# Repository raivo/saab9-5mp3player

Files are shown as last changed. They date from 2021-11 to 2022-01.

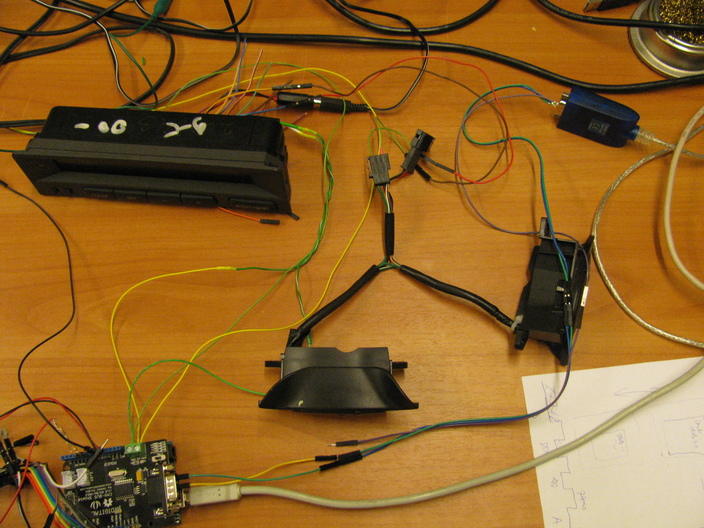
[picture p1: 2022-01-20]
images/IMG_0596.JPG

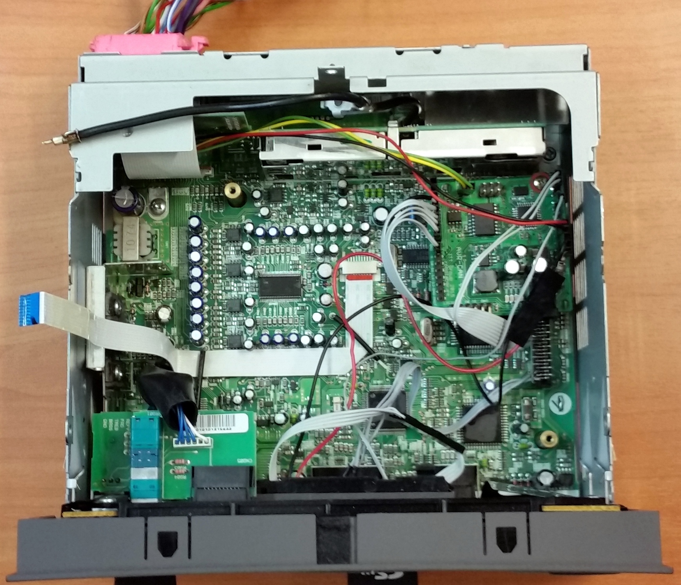
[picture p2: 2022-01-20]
images/20160216_161045.jpg

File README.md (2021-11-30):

# saab9-5mp3player
SAAB 9-5 OG MP3 player for original head unit

MP3 player upgrade for SAAB 9-5 OG OEM stereo

Description

MP3 module for SAAB 9-5 original stereo is a set of hardware and software specially designed for SAAB 9-5 (1998-2005) by replacing old Tape module with new MP3 music player. Music can be played from SD card, USB stick or Aux in (e.g. phone, etc.). MP3 player is controlled over steering wheel buttons and SID buttons. As an option it is possible to have also IR remote control function.

MP3 player fits to SAAB 9-5 model years 1998-2005 without navigation and with Tape module.

Features
Playing MP3 music from SD-card or USB stick
Audio input (Aux in) standard 3,5 mm plug
Equalizer (4 channels)
Song repeat
Next and previous song switching
Moving forward by 10 songs
Some information is showed in SID

Functionality

Steering wheel buttons
SEEK >>	Next song
SEEK <<	Previous song
NXT	10 song forward	Every press moves 10 songs forward
NXT (3 sec)	Moving to song nr.1	Sound signal on SID
SRC (TAPE)	MP3 player ON	LED will switch ON on MP3 player panel. During playback LED is blinking.

SID
SET	Equalizer	Short sound notification on SID
CLEAR	Repeat on/off	Short sound notification on SID

Connection
Module consists of AVR-CAN microcontroller, MP3 player, panel (3D printed), cables and fastenings needed for installation. MP3 Player is installed into Tape insert socket and microcontroller replacing the mechanical tape mechanism inside the stereo. Installation needs electronic skills, including soldering and reading electronic documentation.

Video: https://youtu.be/o2rh0J5VbTw

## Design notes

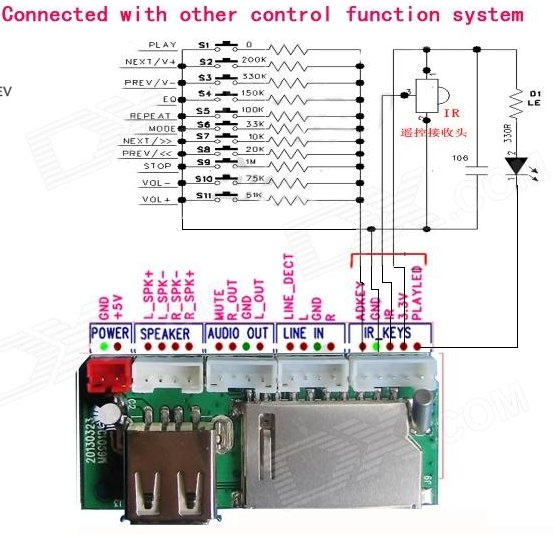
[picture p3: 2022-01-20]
images/MP3_player.jpg

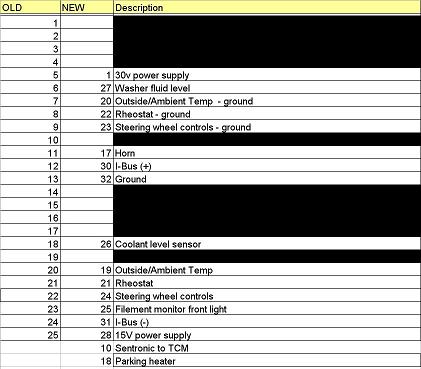
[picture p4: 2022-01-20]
images/SID_ühendused.jpg

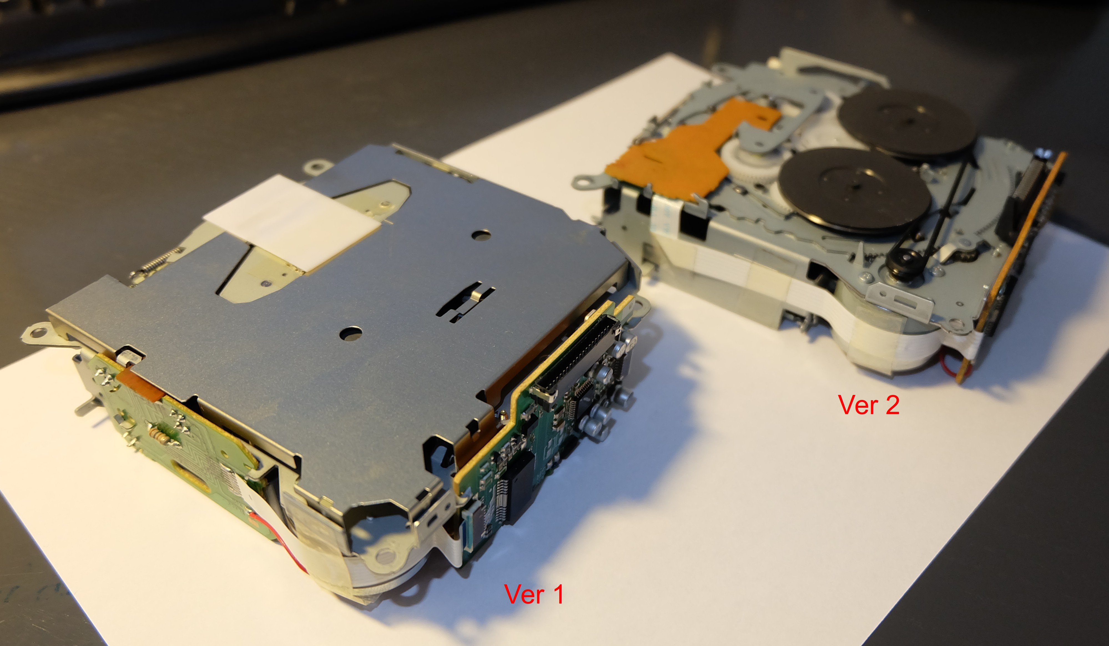
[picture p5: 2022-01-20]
images/Saab95_tapes_side.JPG

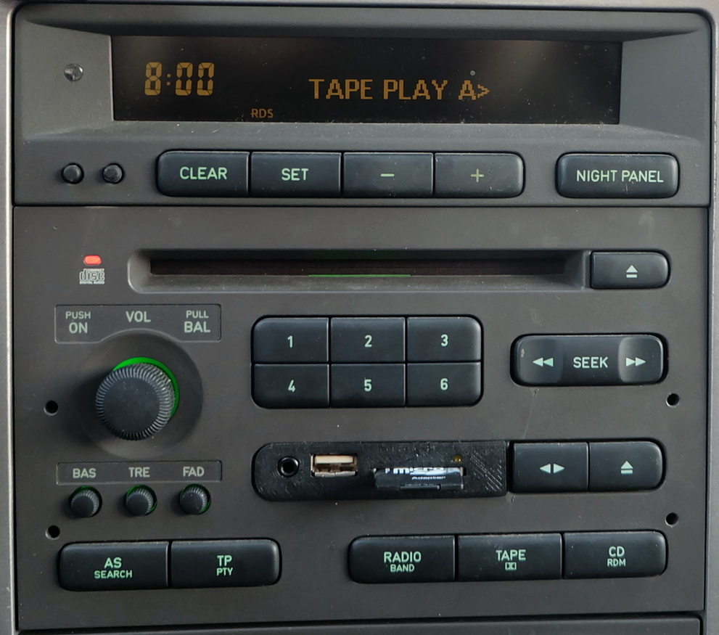
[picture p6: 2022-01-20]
images/makk.JPG

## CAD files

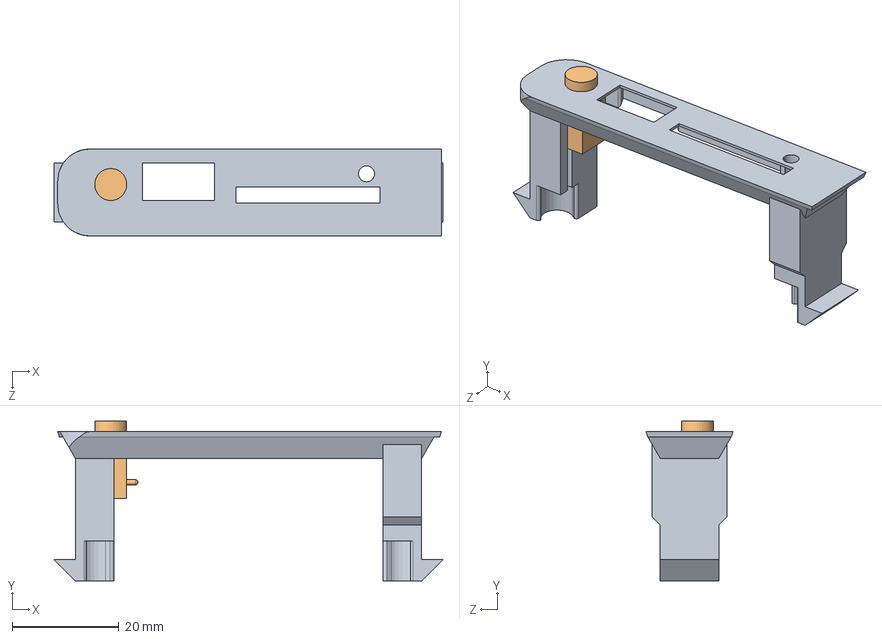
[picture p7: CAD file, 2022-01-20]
cad/Assem1.SLDASM
73.0 x 30.0 x 16.3 mm
Korpus
Stereo

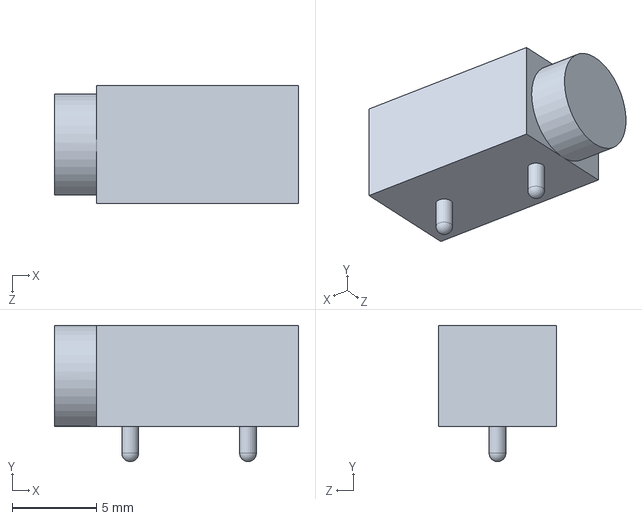
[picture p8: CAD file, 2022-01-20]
cad/Stereo.SLDPRT
14.5 x 8.10 x 7.00 mm

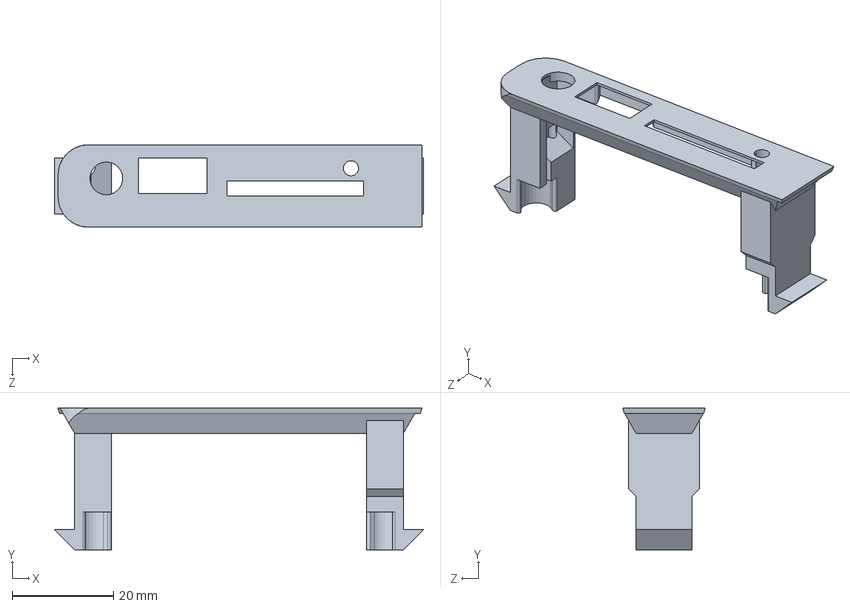
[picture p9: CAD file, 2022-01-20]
cad/Korpus.SLDPRT
73.0 x 28.0 x 16.3 mm

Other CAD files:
cad/Korpus.STL

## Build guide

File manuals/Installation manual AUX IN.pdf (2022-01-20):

# Installation manual

## AUX input for SAAB 9-5 original stereo

AUX input for SAAB 9-5 original stereo instead of TAPE player. During the installation Tape unit will be removed from STEREO unit and will be no longer available. Instead AUX input is used and Tape functionality will be simulated to head unit to avoid audio cut off and tape error.

The product includes tape simulator hardware and software, 3.5 mm audio input connector, necessary cables and fastenings.

NB! Wherever possible we recommend to order installation from manufacturer, please contact with info@ittgroup.ee or by phone +3726566614 for more information. Following this manual is in your own risk and ITT Group is not taking any responsibilities of damage your unit or even car data communication system.

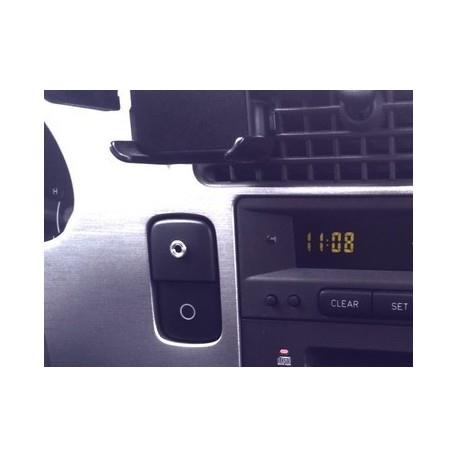
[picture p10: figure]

Document version 1.0

Date 02/2106

ITT Group
Akadeemia tee 21, Tallinn, Estonia
+3725163560, info@ittgroup.ee
Video guide is available in youtube channel: www.youtube.com/ittgrouptallinn

### STEP 1. Identify TAPE version and unsolder main connector plug

Before the installation (and order) one must identify the TAPE version fitted into STEREO unit. Older versions (Ver 1) have different signal logic and tape connector compared with newer version (Ver 2). According to the version different TAPE simulator software is needed for controller. This information have to be sent to manufacturer before product can be sent out to customer.

Images below help to identify the TAPE version inside the STEREO unit.

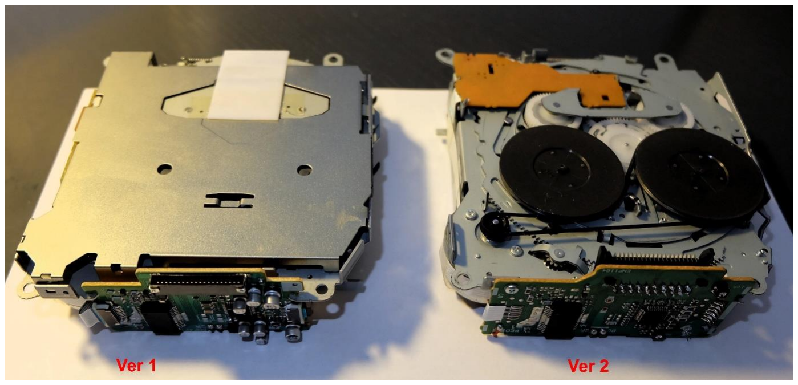
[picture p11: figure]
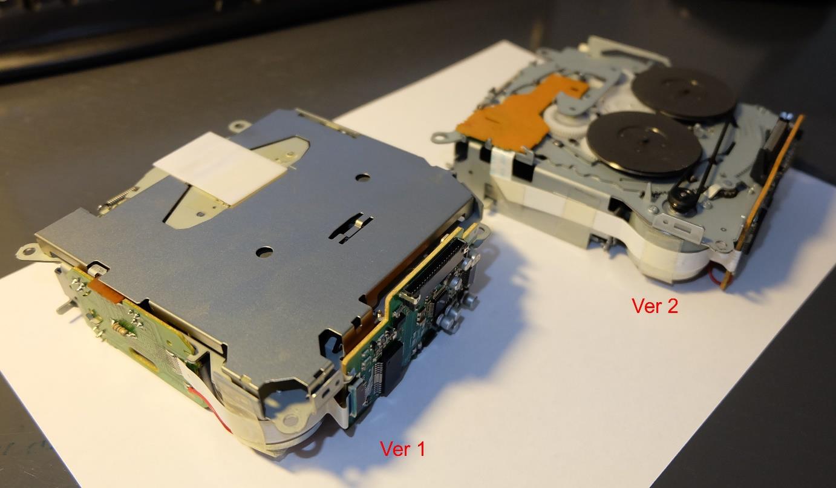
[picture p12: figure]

After removing TAPE player unsolder the main connector on the deck board. TAPE player itself is not needed anymore.

### STEP 2. Solder TAPE Simulator cable

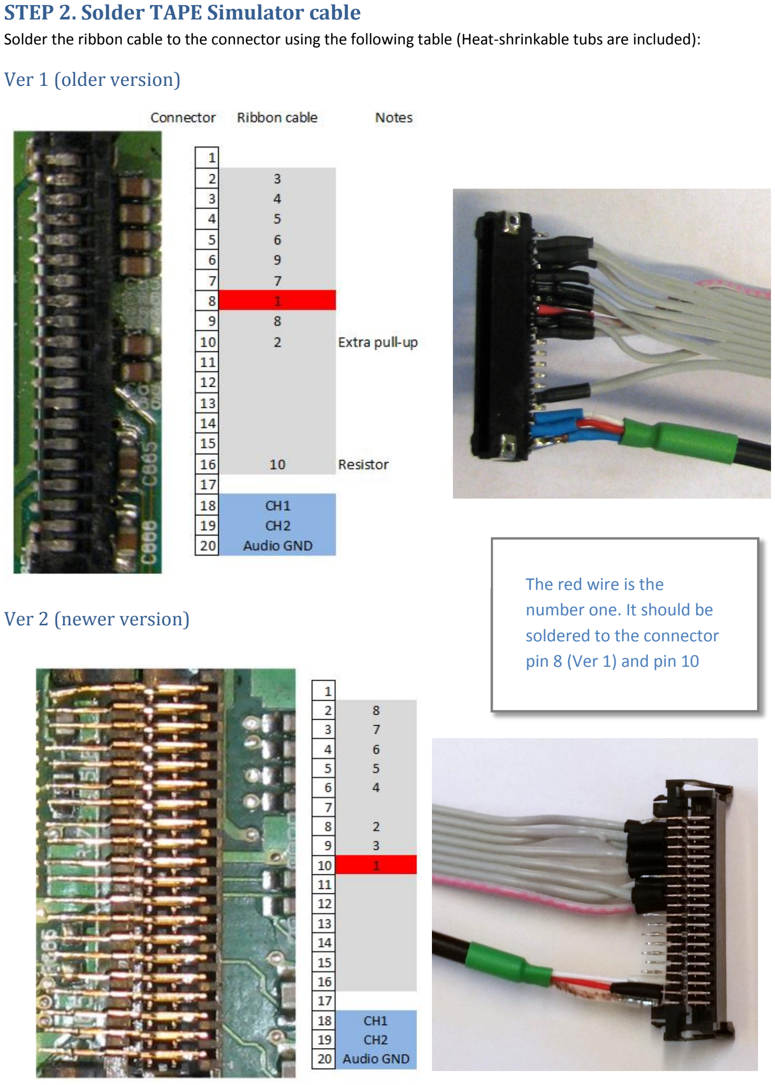
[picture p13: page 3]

The red wire is the
number one. It should be
soldered to the connector
pin 8 (Ver 1) and pin 10

Solder the ribbon cable to the connector using the following table (Heat-shrinkable tubs are included):

### Ver 1 (older version)

### Ver 2 (newer version)

### STEP 3 Solder power cables

Power is taken from remote antenna output. Power cables are soldered to the main STEREO connector board on the back side of unit.

NB! CAN cables are not needed for this case as seen in picture!

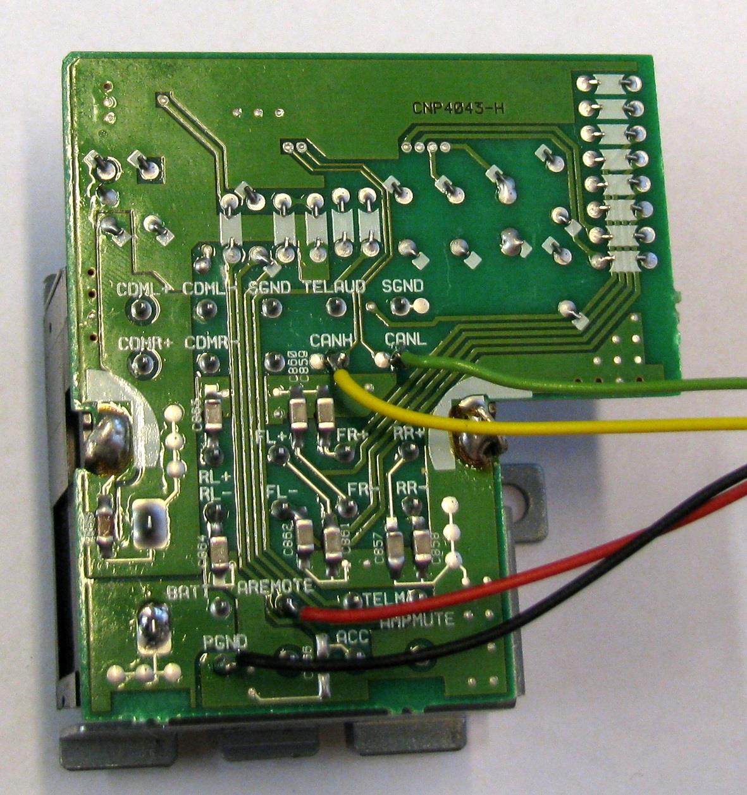
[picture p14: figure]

### STEP 4 Connect simulator plug and install the controller board

### Ver 2 Ver 1

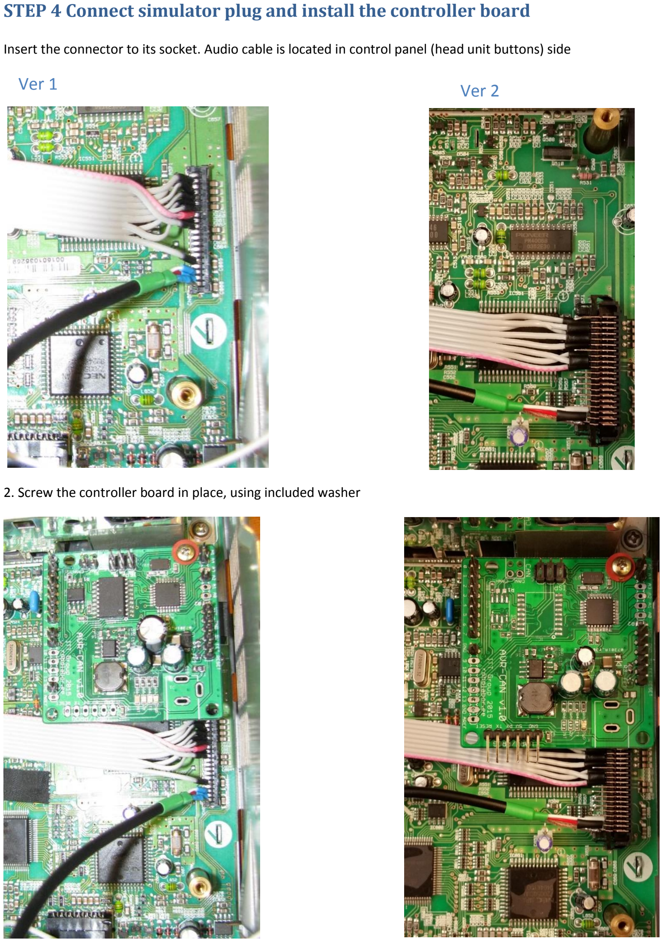
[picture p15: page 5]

Insert the connector to its socket. Audio cable is located in control panel (head unit buttons) side

2. Screw the controller board in place, using included washer

### STEP 5 Connect all wires to controller board

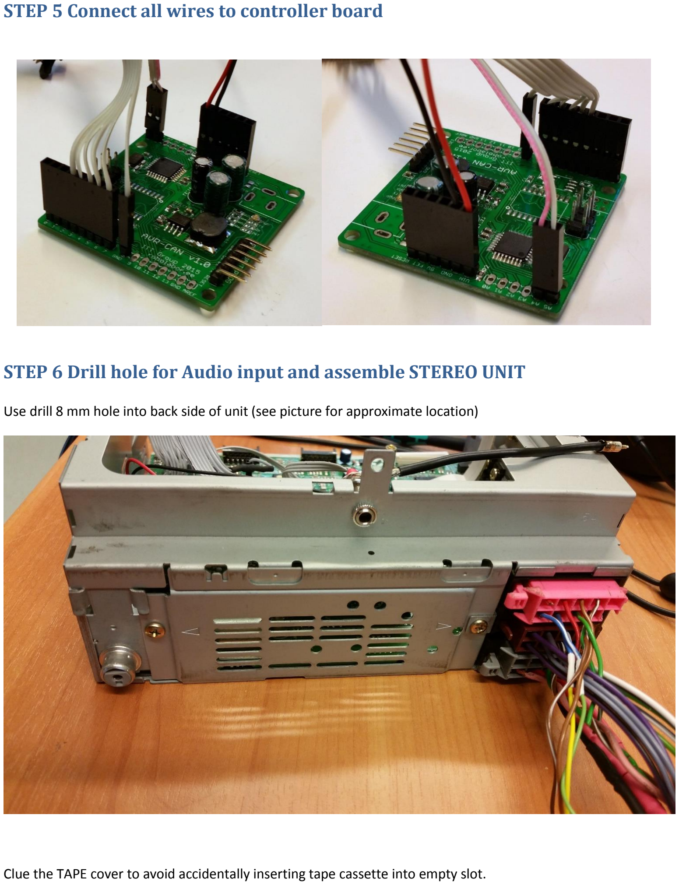
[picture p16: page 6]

### STEP 6 Drill hole for Audio input and assemble STEREO UNIT

Use drill 8 mm hole into back side of unit (see picture for approximate location)

Clue the TAPE cover to avoid accidentally inserting tape cassette into empty slot.

Make frontend socket for AUX IN (e.g. empty button slot)

Example:

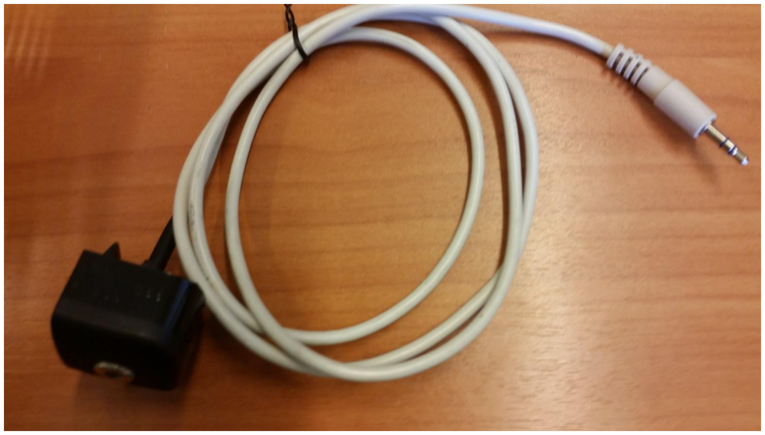
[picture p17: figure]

Assembly remaining parts and test the system.

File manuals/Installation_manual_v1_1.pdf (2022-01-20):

# Installation manual

## MP3 player module for SAAB 9-5 with AUX IN

MP3 player module for SAAB 9-5 original stereo is a set of hardware and software specially designed for SAAB 9-5 (1998-2005) by replacing old Tape module with new MP3 music player. Music can be played from SD card, USB stick or Aux in (e.g. phone, etc.). MP3 player is controlled over steering wheel buttons and SID buttons. As an option it is possible to order IR remote control option. MP3 player fits into SAAB 9-5 model years 1998-2005 without navigation and with Tape module original stereo.

NB! Wherever possible we recommend to order installation from manufacturer, please contact with info@ittgroup.ee or by phone +3726566614 for more information. Following this manual is in your own risk and ITT Group is not taking any responsibilities of damage your unit or even car data communication system.

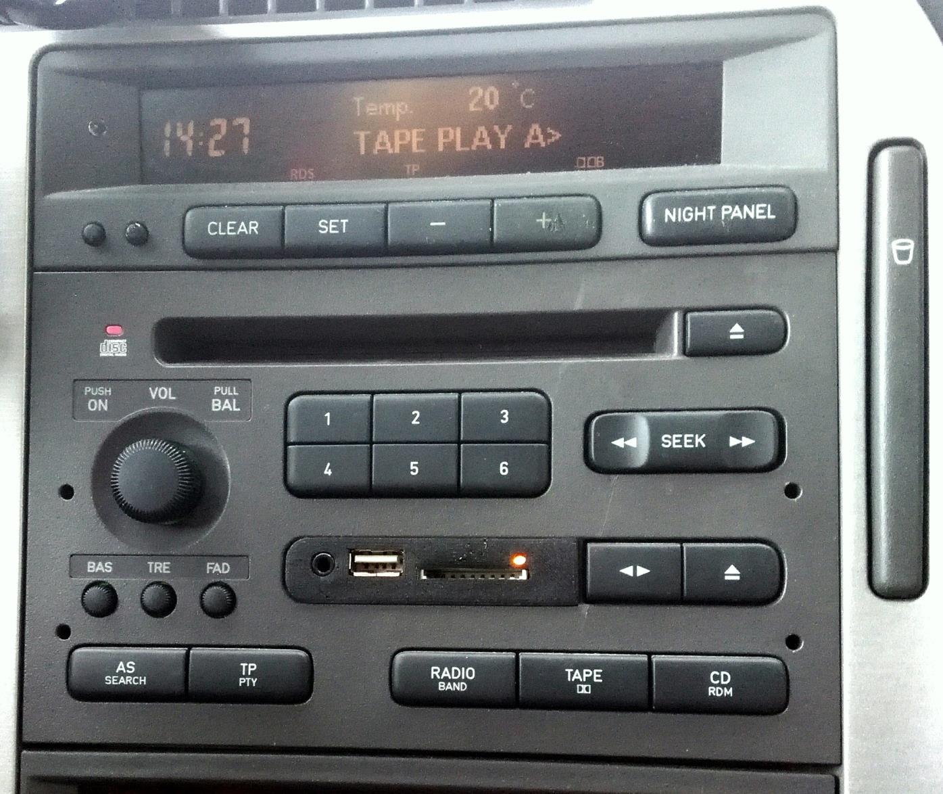
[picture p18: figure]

Document version 1.1

Date 09/2106

ITT Group
Akadeemia tee 21, Tallinn, Estonia
+3725163560, info@ittgroup.ee
Video guide is available in youtube channel: www.youtube.com/ittgrouptallinn

### STEP 1. Identify TAPE version and unsolder main connector plug

Before installation the TAPE version fitted into STEREO unit should be identified. Older versions usually on MY 1998-2002 (Ver 1) have different signal logic and tape connector compared with newer version, usually on MY 2002-2005 (Ver 2). According to the version user should set jumper on controller board (see later).

Images below help to identify the TAPE version inside the STEREO unit. Pay attention to the connector location.

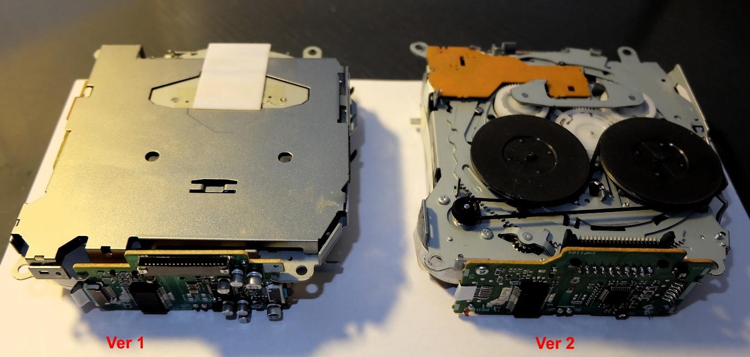
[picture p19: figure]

After removing TAPE player unsolder the main connector on the deck board. TAPE player itself is not needed anymore. Hot air blower with small nozzle is a good tool for unsoldering the main connector

### STEP 2. Solder TAPE Simulator cable

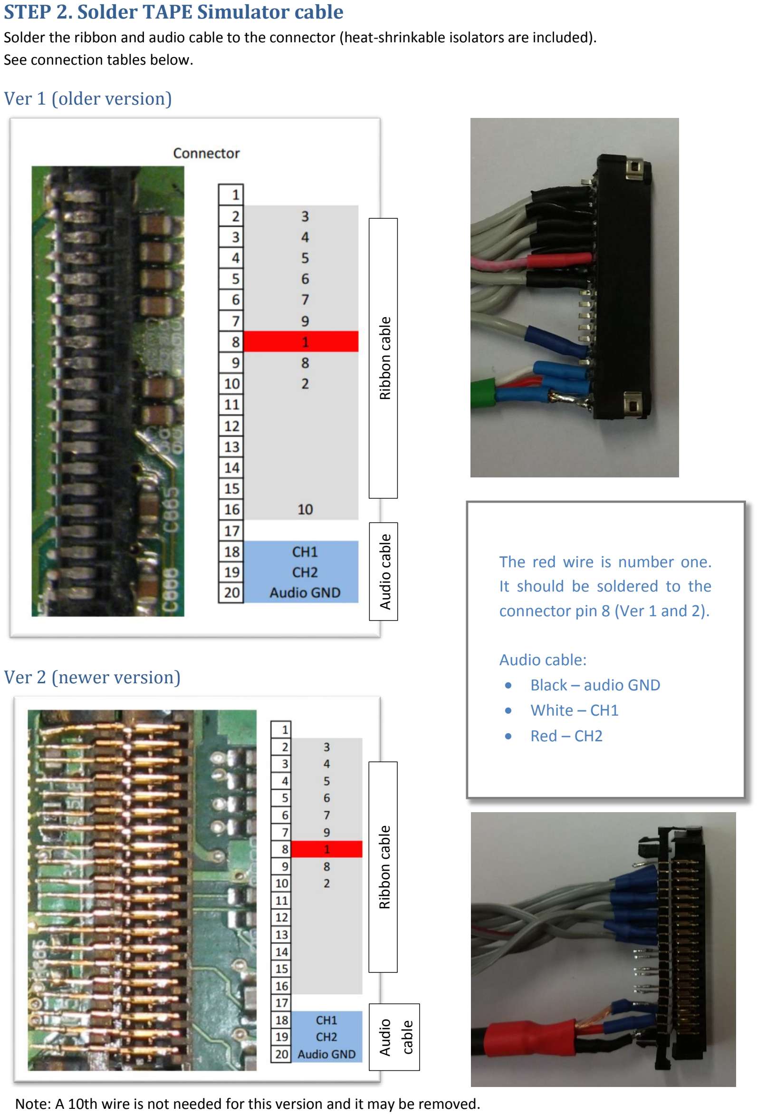
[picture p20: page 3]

The red wire is number one. It should be soldered to the connector pin 8 (Ver 1 and 2).

Audio cable:
- Black – audio GND
- White – CH1
- Red – CH2

Solder the ribbon and audio cable to the connector (heat-shrinkable isolators are included). See connection tables below.

### Ver 1 (older version)

### Ver 2 (newer version)

Audio cable Ribbon cable Audio

cable

Ribbon cable

Note: A 10th wire is not needed for this version and it may be removed.

### STEP 3 Solder CAN and power cables

Power is taken from remote antenna output. Power and CAN wires are soldered to the main STEREO connector board on the back side of unit.

- CAN H is yellow wire
- CAN L is green wire


### 1. Insert the audio input AUX IN

connector to its slot.

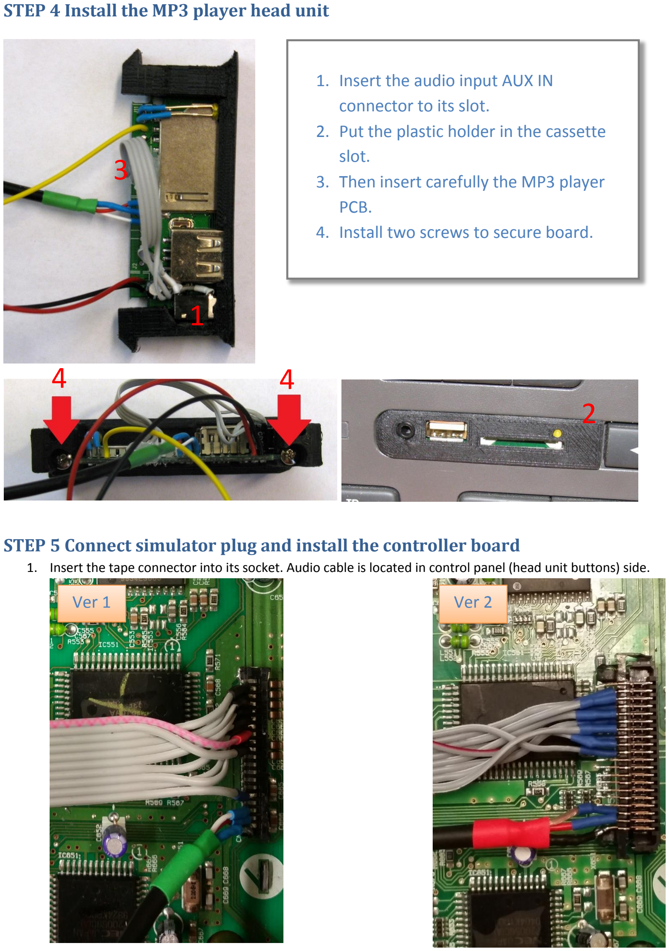
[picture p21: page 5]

### 2. Put the plastic holder in the cassette

slot.

### 3. Then insert carefully the MP3 player

PCB.
4. Install two screws to secure board.

### STEP 4 Install the MP3 player head unit

### STEP 5 Connect simulator plug and install the controller board

1. Insert the tape connector into its socket. Audio cable is located in control panel (head unit buttons) side.

1

2

3

4 | 4
Ver 1 | Ver 2

### Ver 1 (older version) A1-A2

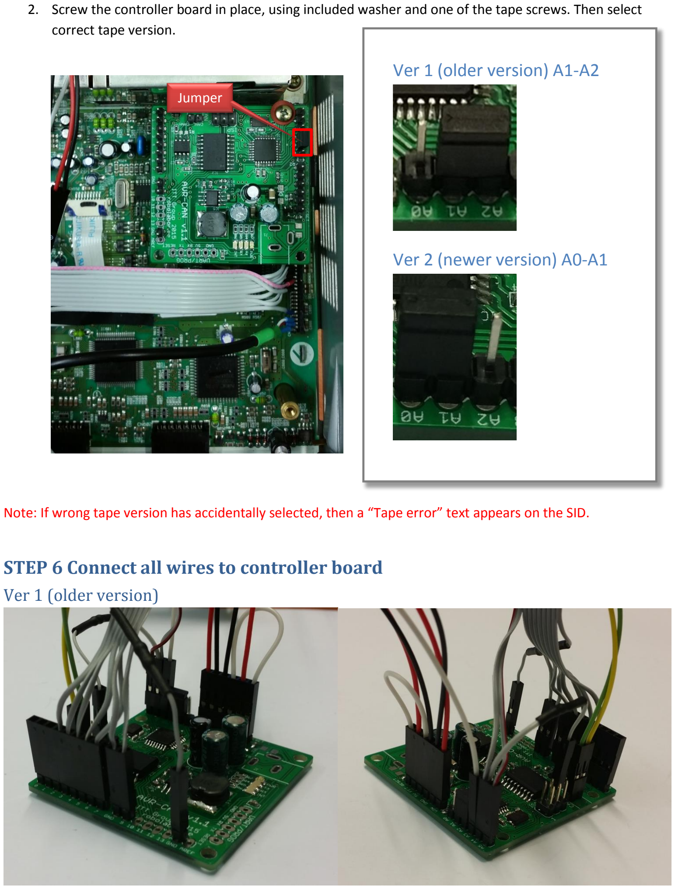
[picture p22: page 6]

### Ver 2 (newer version) A0-A1

2. Screw the controller board in place, using included washer and one of the tape screws. Then select correct tape version.

Note: If wrong tape version has accidentally selected, then a “Tape error” text appears on the SID.

### STEP 6 Connect all wires to controller board

### Ver 1 (older version)

Jumper

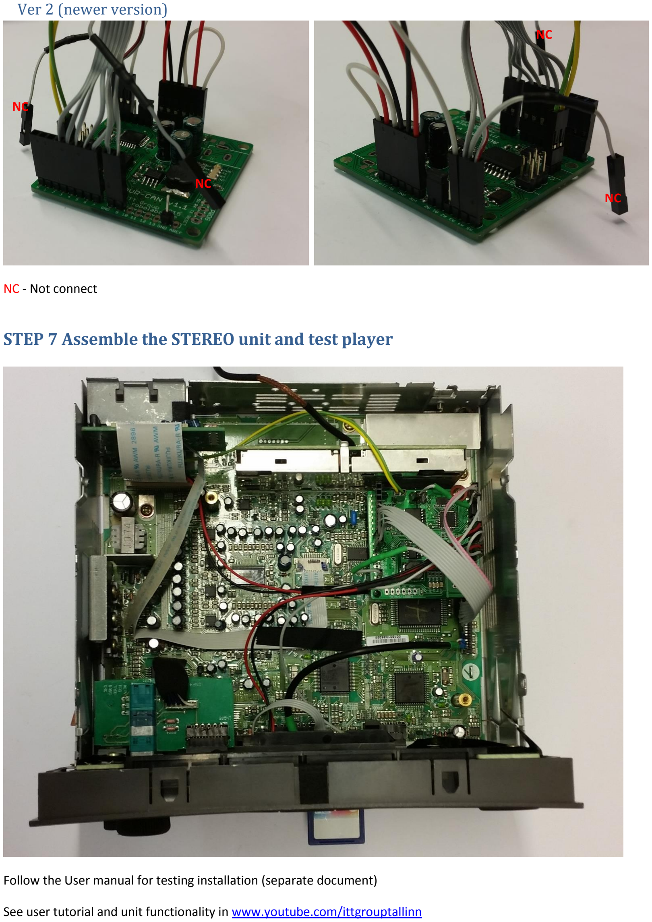
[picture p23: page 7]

### Ver 2 (newer version)

NC - Not connect

### STEP 7 Assemble the STEREO unit and test player

Follow the User manual for testing installation (separate document)

See user tutorial and unit functionality in www.youtube.com/ittgrouptallinn

NC

NC

NC

NC

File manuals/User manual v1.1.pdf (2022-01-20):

# User manual

## MP3 player module for SAAB 9-5 with AUX IN

MP3 player module for SAAB 9-5 original stereo is a set of hardware and software specially designed for SAAB 9-5 (1998-2005) by replacing old Tape module with new MP3 music player. Music can be played from SD card, USB stick or Aux in (e.g. phone, etc.). MP3 player is controlled over steering wheel buttons and SID buttons. As an option it is possible to order IR remote control option. MP3 player fits to SAAB 9-5 model years 1998-2005 without navigation and with Tape module.

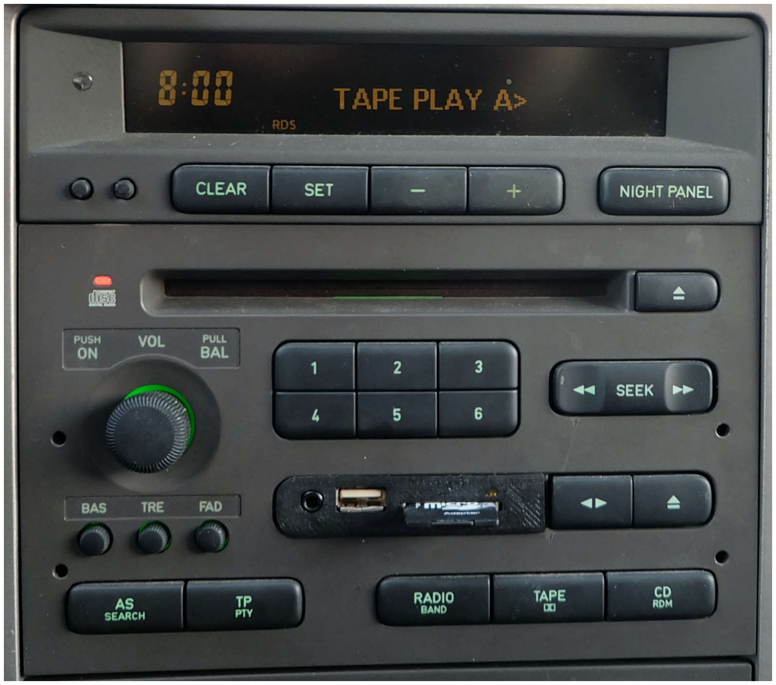
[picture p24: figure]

Document version 1.1

Date 09/2106

ITT Group
Akadeemia tee 21, Tallinn, Estonia
+3725163560, info@ittgroup.ee
Video guide is available in Youtube channel: www.youtube.com/ittgrouptallinn

### Features

- Playing MP3 music from SD-card or USB stick (with low power consumption)
- Audio input (Aux in) standard 3,5 mm plug
- Equalizer (4 channels)
- Song repeat
- Next and previous song switching
- Moving forward by 10 songs
- Some information is showed in SID

PS We recommend to use SD cards for playing music instead of USB stick. See also optional SD card holder modification for SAAB 9-5 coin holder. http://www.ittgroup.ee/en/car-electronics/849-sd-card-modification-for-saab-9-5-coin-holder.html

### Functionality

To switch MP3 player use steering wheel button SRC or head unit button TAPE

TAPE Playing A(B) > will be displayed on SID

Depending whether the SD card or USB stick is inserted to MP3 player, music starts playing automatically. It is suggested to use either USB stick or SD card on the same time, not both. When connecting audio cable to AUX IN the player output is automatically switched to AUX input audio.

Controlling song selection is done with steering wheel buttons.

### Steering wheel buttons

SEEK >> | Next song
SEEK << | Previous song

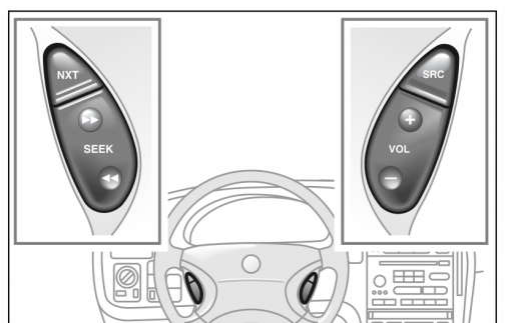
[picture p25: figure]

NXT | 10 song forward | Every press moves 10 songs forward
NXT (3 sec) | Moving to song nr.1 | Sound signal on SID
SRC (TAPE) | MP3 player ON | LED will switch ON on MP3 player panel. During playback LED is blinking.

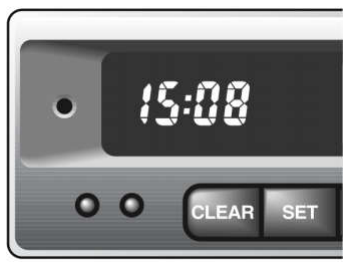
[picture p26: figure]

### SID (SAAB Information Display)

Sound and song repeat options are controlled by SID buttons

SET | Equalizer | Short sound notification on SID
CLEAR | Repeat on/off | Short sound notification on SID

### User tips and remarks

### Finding songs

- NXT buttons moves 10 songs forward. If there are less songs than current counter, last song starts playing. Counter will be reset every switch off of the main head unit. However, MP3 player remembers last song played from the SD card and continues same song play even if other SD cards are used meanwhile.
- Fast switching of NXT button is allowed. For example, if you want to move to song 50, press 5 times NXT button and then wait until song no. 50 starts playing. Moving to next or previous song SEEK button in steering wheel is used. However, moving back by 10 songs is not directly possible. To do that, first reset counter NXT (3 s) and then move to desired number (e.g. no. 40) by pressing NXT button (4 times).
- SEEK button on steering wheel is used for moving next or previous song. SEEK button on head unit cannot be used for same purpose. In case of pressing SEEK button on steering wheel too fast a SEEK state of tape function can be stay on and no sound is allowed. If this is the case (SID is displaying: TAPE SEEK >>) press head unit SEEK button on middle position. This will return playing state and sound is switched on again.
- There is no way to move by folders in SD card or USB stick. Instead we suggest to use different SD cards for different music to reduce music files in one card. In this case it is easier to remember and navigate.

### Messages on SID

- Different functions are displaying messages on the SID. When MP3 module is active common message TAPE PLAY A > or TAPE PLAY B > is displayed. There is no difference is it showing A or B.
- By using NXT button to move to next 10. Song a short message: SONG NR xx is displayed on SID. Message is displayed after button reading timeout is reached (counting button press and waiting timeout 0,5 sec). After timeout song number is sent to MP3 module and message is sent to SID.
- Equalizer (SET button) has 4 different modes. EQ1 … EQ4 messages are sown on SID.
- Repeat song (CLR button) has 2 states. One song repeats on and repeat off. Appropriate message is shown on SID.
- SID messages are shown 1 second. However, if ignition switch is on or car is running messages are shown on different durations up to 1 second. Duration time is random and depends how fast original stereo unit overwrites the MP3 module messages.

### Troubleshooting

- No sound, SID display: TAPE SEEK >>
- Press head unit SEEK button middle position (text SEEK between right and left arrows)
- No sound, SID display: TAPE PLAY A/B> or just TAPE
- Remove SD card, USB stick and AUX in plug. Insert again only one music source (e.g. SD card) and make sure there is mp3 music files
- Move head unit to Radio, check if sound is produced and then move back to Tape
- Switch off head unit for 10 seconds and then switch it on again
- No sound, SID display: TAPE ERR xx
- Switch off head unit for 10 seconds and then switch it on again
- Contact manufacturer: Tape simulator is either not working of lost contact between simulator or head unit.

### Optional features

- MP3 module can be equipped with remote control. This option is not installed by default but can be ordered separately. Remote control device offers some additional features like moving to exact song (e.g. song no. 156) and set internal volume level.

See user tutorial video and unit functionality in Youtube channel www.youtube.com/ittgrouptallinn

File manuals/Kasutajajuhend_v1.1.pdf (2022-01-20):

# Kasutajajuhend

## SAAB 9-5 MP3 muusikamoodul koos audio sisendiga

SAAB 9-5 MP3 muusikamoodul on riistvara ja tarkvara komplekt, mis on spetsiaalselt arendatud SAAB 9-5 (1998-2005) jaoks asendades vana kassettmaki mooduli uue MP3 muusikamängijaga. Muusikat saab mängida SD kaardilt, USB mälupulgalt või AUX in-ist (nt telefon vms). MP3 mängijat juhitakse rooli- ja SID nuppudega. Soovi korral saab tellida IR puldi lisana. MP3 mängija sobib SAAB 9-5 mudelitele, mis on toodetud vahemikus 1998-2005, millel on kassettmaki moodul.

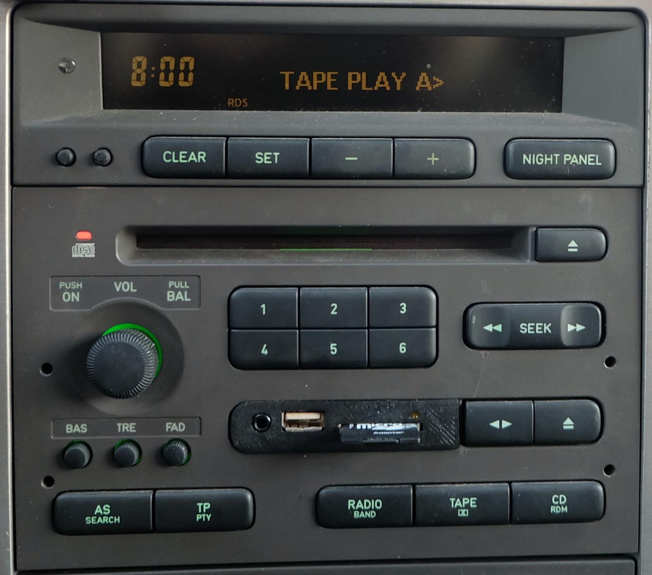
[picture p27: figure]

Dokumendi versioon 1.1

Kuupäev 09/2106

ITT Group
Akadeemia tee 21, Tallinn, Eesti
+3725163560, info@ittgroup.ee
Videojuhend on saadaval youtube´is aadressil: www.youtube.com/ittgrouptallinn

### Omadused

- Mängib MP3 muusikat SD kaardilt ja USB mälupulgalt
- Audio sisend (Aux in) standard 3,5 mm pistik
- Ekvalaiser (4 kanalit)
- Laulukordus
- Eelmise ja järgmise laulu lüliltus
- Edasi liikumine 10 laulu kaupa
- Osa infot kuvatakse SID ekraanil

### Funktsionaalsus

MP3 muusikamängija käivitamiseks saab valida roolil oleva SRC nupuga TAPE või makilt otse nupuga TAPE.

SID ekraanil kuvatakse TAPE PLAY A(B)

Kui SD kaart või USB pulk sisestatakse MP3 mängijasse, hakkab muusika automaatselt mängima. Soovitav on kasutada, kas USB mälupulka või SD kaarti, mitte mõlemat korraga. Kui audio kaabel ühendatakse AUX IN pistikusse, siis lülitatakse mängija väljund automaatselt välise sisendi peale.

Laulude valikut saab juhtida roolil olvate nuppude abil.

### Roolinupud

SEEK >> | Järgmine laul
SEEK << | Eelmine laul

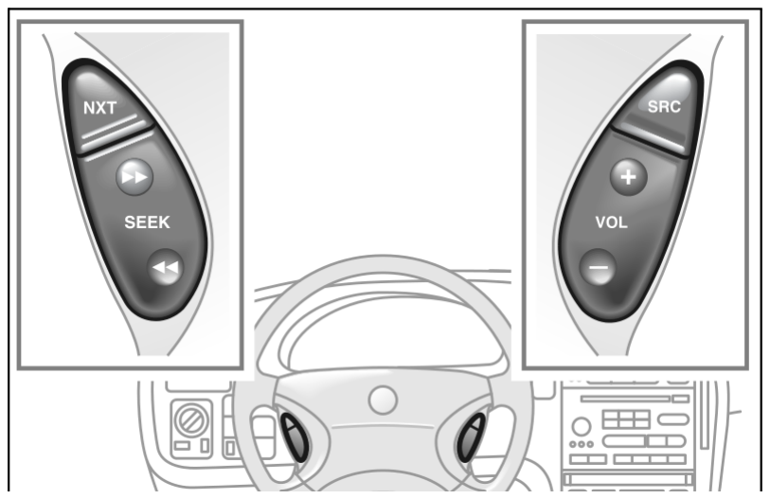
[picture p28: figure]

NXT | 10 laulu edasi | Iga vajutus liigub 10 laulu edasi
NXT (3 sec) | Liigub laulule nr. 1 | Helisignaal SID-il
SRC (TAPE) | MP3 mängija ON (sisse) | LED lülitub sisse MP3 mängija paneelil. Laulu esitamisel LED vilgub.

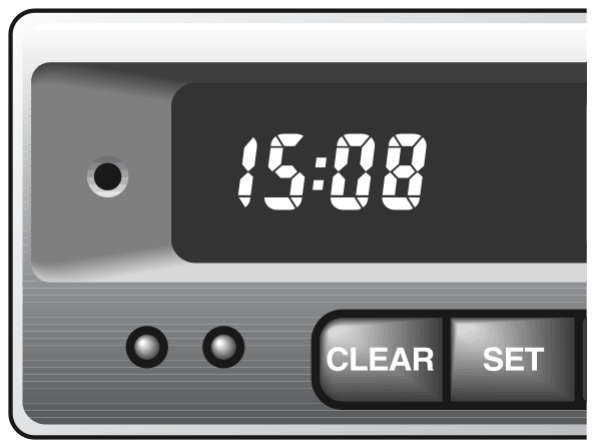
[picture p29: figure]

### SID (SAABi infonäidik)

Heli ja laulu kordamise valikuid kontrollitakse SID nuppudega

SET | Ekvalaiser | Lühike helisignaalil SID-il
CLEAR | Kordus on/off (sisse/välja) | Lühike helisignaal SID-il

### Kasutaja nõuanded ja märkused

### Laulude otsimine

- NXT nupp liigub 10 laulu edasi. Kui mälukandjal on vähem laule, siis hakkab mängima viimane laul. Loendaja lähtestab käsu uuesti peale iga väljalülitust juhtseadmest. MP3 mängija mäletab viimast SD kaardilt mängitud laulu ja jätkab sama laulu mängimist isegi siis, kui vahepeal on kasutatud teisi SD kaarte.
- Lubatud on ka NXT nupu kiire lülitamine. Näiteks, kui sa soovid liikuda 50 laulu edasi, vajuta 5 korda NXT nuppu ja oota kuni laul nr. 50 hakkab mängima. Roolil asuva SEEK nupu abil saab liikuda järgmise või eelmise laulu peale. 10 laulu kaupa tagasi liikumine pole otseselt võimalik. Kui seda ikkagi teha soovitakse, siis tuleb esiteks liikuda esimesele laulule NXT (3 s) ja siis liikuda soovitud numbrini (nt nr 40) vajutades nuppu NXT (4 korda).
- Roolirattal paiknevat SEEK nuppu kasutatakse eelmise või järgmise laulu peale liikumiseks. Juhtseadmel paiknevat SEEK nuppu ei saa kasutada samal eesmärgil. Kui vajutada SEEK nuppu roolirattal liiga kiiresti, siis mängija SEEK status jääb sisse lülitatuks ja heliväljastamine pole lubatud. Sellisel juhul (SID kuvab: TAPE SEEK >>) vajutada juhtseadme SEEK nupp keskmist positsiooni. See käsklus taastab seadmel heli mängimise ja lülitab seadme uuesti sisse.
- Puudub võimalus liikuda SD kaardil või USB pulgal olevate kaustade vahel. Selle asemel on soovitav kasutada erinevaid SD kaarte erineva muusika jaoks. Nii on ka lihtsam meelde jätta ja navigeerida.

### SID´i teated

- SID-il kuvatakse erinevaid funktsionaalseid teateid. Kui MP3 moodul on aktiveeritud, siis ilmub näidikule teade TAPE PLAY A > või TAPE PLAY B >. Pole oluline kas näidikule kuvatakse A või B.
- Kasutades NXT nuppu, saab liikuda edasi 10 laulu kaupa. SID-ile kuvatakse lühike info laulu kohta: SONG NR xx. Teade kuvatakse peale nupule vajutamist (loenduri nupule vajutus ja ooteaeg peale seda 0,5 sek). Peale ooteaega saadetakse laulu number MP3 mängijale ja SID-ile.
- Ekvalaiseril (SET nupp) on 4 erinevat reźiimi. SID-il kuvatakse teated EQ1 … EQ4.
- Laulu kordamisel (CLR nupp) on 2 staatust. Laulu kordamine sisse lülitatud ja laulu kordamine välja lülitatud. Vastav teade kuvatakse ka SID näidikul.
- SID-i teated kuvatakse 1 sekundi jooksul. Kui auto käib, siis kuvatakse teated erineva kestvusega maksimaalselt kuni 1 sekundi jooksul. Kestvuse aeg on juhuslik ja sõltub, kui kiiresti originaal kassetimängija üksus kirjutab üle MP3 mooduli teated.

### Probleemide lahendamine

- Puudub heli, SID-il kuvatud: TAPE SEEK >>
- Vajutada juhtseadmel SEEK nupp keskmist positsiooni (noolte vahel tekst SEEK)
- Puudub heli, SID-il kuvatud: TAPE PLAY A/B>
- Eemalda SD kaart, USB pulk või AUX in pistik. Sisesta uuesti ainult üks muusika allikas (nt SD kaart) ja kontrolli üle, et tegemist oleks MP3 muusikafailidega
- Lülita stereo Raadio reziimi, kontrolli kas heli on olemas oota paar sekundit ja lülita uuesti muusikamängijaga režiimi (TAPE)
- Lülita stereo 10 sekundiks välja ja uuesti sisse
- Puudub heli, SID-il kuvatud: TAPE ERR xx
- Lülita juhtseade 10 sekundiks välja ja uuesti sisse
- Võta ühendust tootjaga: Muusikamängija simulaator ei pruugi töötada ühenduse kadumise tõttu juhtseadme ja simulaatori vahel.

### Võimalikud lisad

- MP3 moodulile on võimalik lisada kaugjuhtimispult. See lisa pole vaikimisi seadistatud, vaid tuleb eraldi tellida. IR puldi abil saab kasutada mõningaid lisavõimalusi nagu liikumine kindla laulu peale (nt laul nr 156) ja seadistada ning muuta mooduli helitugevust.
Kasutusjuhend saadaval youtube´is www.youtube.com/ittgrouptallinn

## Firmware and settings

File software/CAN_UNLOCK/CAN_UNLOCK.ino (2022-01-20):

// SAAB 9-5 stereo project
//
// Sends unlock code
// 
// CAN-BUS Shield, Arduino UNO
// 
// ITT Group
// 20.02.2015
// ver 0.1
//

#include <TimerOne.h>                          
#include <SPI.h>
#include "mcp_can.h"

#define TIMER_US 1000                         // 100mS set timer duration in microseconds 

// DECK PIN setup:
const int Code1 =             A5;  // For old radio
const int Code2 =             A4;  // For new radio

// CAN shield PIN setup:
MCP_CAN CAN(10); // Set CS to pin 10

unsigned char Flag_Recv = 0;
unsigned char len = 0;
unsigned char buf[8];


unsigned char code_1[8] = {0, 0, 0, 0, 0x90, 0x51, 0x83, 0}; // Old
unsigned char code_2[8] = {0, 0, 0, 0, 0x95, 0x19, 0x12, 0}; // New

int enableState = 0;


void CAN_setup()
{
START_INIT:

    if(CAN_OK == CAN.begin(CAN_47K62BPS))                   // init can bus : baudrate = 47.62k
    {
        Serial.println("CAN BUS init ok!");
    }
    else
    {
        Serial.println("CAN BUS init fail");
        Serial.println("Init CAN BUS again");
        delay(100);
        goto START_INIT;
    }
    
    attachInterrupt(0, MCP2515_ISR, FALLING); // start interrupt    

}

void setup() 
{
 
  pinMode(Code1, INPUT); 
  pinMode(Code2, INPUT); 

  Timer1.initialize(TIMER_US);                  // Initialise timer 1
  Timer1.attachInterrupt( timer1Isr );           // attach the ISR routine here
  
  Serial.begin(115200); 
 
  CAN_setup();
}

void loop()
{
  
  if (digitalRead(Code1)) 
  {
         CAN.sendMsgBuf(0x4A0, 0, 8, code_1); 
         Serial.println("Code1");         
  }     
  else 
  {
         CAN.sendMsgBuf(0x4A0, 0, 8, code_2);
         Serial.println("Code2");         
  }  
  delay(1000); 
  
}

void MCP2515_ISR()
{
     Flag_Recv = 1;
}

// --------------------------
// timerIsr() 100 milli second interrupt ISR()
// Called every time the hardware timer 1 times out.
// --------------------------
void timer1Isr()
{       
    if(Flag_Recv)                   // check if get data
    {    
        Flag_Recv = 0;                // clear flag
        CAN.readMsgBuf(&len, buf);    // read data,  len: data length, buf: data buf
        if(CAN.getCanId() == 0x290)
        {
        }
        
    }
  
}

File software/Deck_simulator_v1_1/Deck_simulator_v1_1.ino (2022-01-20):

// SAAB 9-5 stereo project
//
// Reads the state of the buttons on the steering wheel over CAN-bus and drive MP3 board. Receive data with interrupt mod. Full simulator for cassete system.
// 
// Riistvara: ITT AVR CAN Board
// 
// ITT Group
// 25.05.2015
// ver 1.1
//

#include <ChibiOS_AVR.h>
#include <TimerOne.h>

//------------------------------------------------------------------------------
//Debug mode. Serial is on
//#define DEBUG 
//------------------------------------------------------------------------------

#define TIMER_US 1000                         // 100mS set timer duration in microseconds 

#define NEW_DECK 1
#define OLD_DECK 0

//------------------------------------------------------------------------------
// Music player subsystem global variables:
//------------------------------------------------------------------------------
unsigned long last_nxt_press_time = 0;
int nxt_flag = 0;
int track_number;
int mute = 0;

//------------------------------------------------------------------------------
// DECK simulator subsystem global variables:
//------------------------------------------------------------------------------
int enableState = 0;

//------------------------------------------------------------------------------
// Version selection switch pin setup
//------------------------------------------------------------------------------
const int ver_switch_supply_pin = A0;  // 5V
const int ver_switch_pin =        A1;  // Signal
const int ver_switch_gnd_pin =    A2;  // GND

int deck_version = 0;

//------------------------------------------------------------------------------
// WorkerThread - run all the system
// 100 byte stack beyond task switch and interrupt needs
//------------------------------------------------------------------------------
static WORKING_AREA(waWorkerThread, 100);

static msg_t WorkerThread(void *arg) 
{
  while (1) 
  {
    //chThdSleepMilliseconds(1); 
    CAN_message_handler();
    mp3_handler();
    SID_CAN_text_handler();    
  }
}
//------------------------------------------------------------------------------
// DeckSimulatorThread - high priority for all deck logic
//------------------------------------------------------------------------------
static WORKING_AREA(waDeckSimulatorThread, 100);

static msg_t DeckSimulatorThread(void *arg) 
{ 
  while (1) 
  {
    if(deck_version)
    {
      new_deck_simulator_handler();
    }  
    else
    {
      old_deck_simulator_handler();
    } 
        
    ir_handler();  
  }
  return 0;
}

//------------------------------------------------------------------------------
void setup() 
{   
  Serial.begin(115200);

  Serial.println("START12");

  // Set version switch pins
  pinMode(ver_switch_supply_pin, OUTPUT); 
  pinMode(ver_switch_gnd_pin, OUTPUT); 
  pinMode(ver_switch_pin, INPUT);  
    
  digitalWrite(ver_switch_supply_pin, HIGH); 
  digitalWrite(ver_switch_gnd_pin, LOW); 

  if(digitalRead(ver_switch_pin))
  {
    Serial.println("Selected NEW deck system");
    deck_version = 1;
    new_deck_simulator_setup();
  }
  else
  {
    Serial.println("Selected OLD deck system");
    deck_version = 0;
    old_deck_simulator_setup();
  }  
  
  ir_subsystem_setup();
   
  music_player_setup();
  
  Timer1.initialize(TIMER_US);                  // Initialise timer 1
  Timer1.attachInterrupt( timer1Isr );          // attach the ISR routine here
  CAN_setup();
  chBegin(mainThread);   
  
  // chBegin never returns, main thread continues with mainThread()
  while(1) {}
}
//------------------------------------------------------------------------------
// main thread runs at NORMALPRIO
//------------------------------------------------------------------------------
void mainThread() 
{
  // start blink thread
  chThdCreateStatic(waDeckSimulatorThread, sizeof(waDeckSimulatorThread),
                          NORMALPRIO + 2, DeckSimulatorThread, NULL);

  // start print thread
  chThdCreateStatic(waWorkerThread, sizeof(waWorkerThread),
                          NORMALPRIO + 1, WorkerThread, NULL);
                          

  while (1) 
  {
    // Do nothing
  }
}
//------------------------------------------------------------------------------
void loop() 
{
 // not used
}

//------------------------------------------------------------------------------
// timer1Isr - PWM signals generation for deck simulator
//------------------------------------------------------------------------------
void timer1Isr()
{   
  if(deck_version)
  {
    new_deck_simulator_PWM_handler();
  }
  else
  {
    old_deck_simulator_PWM_handler();
  }
      
}
